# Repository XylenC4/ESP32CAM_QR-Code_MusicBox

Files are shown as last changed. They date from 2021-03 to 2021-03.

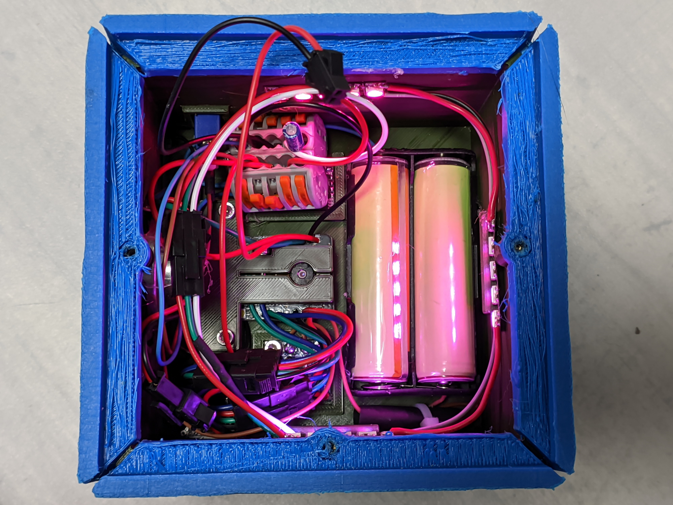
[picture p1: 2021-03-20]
Images/Inside.jpg

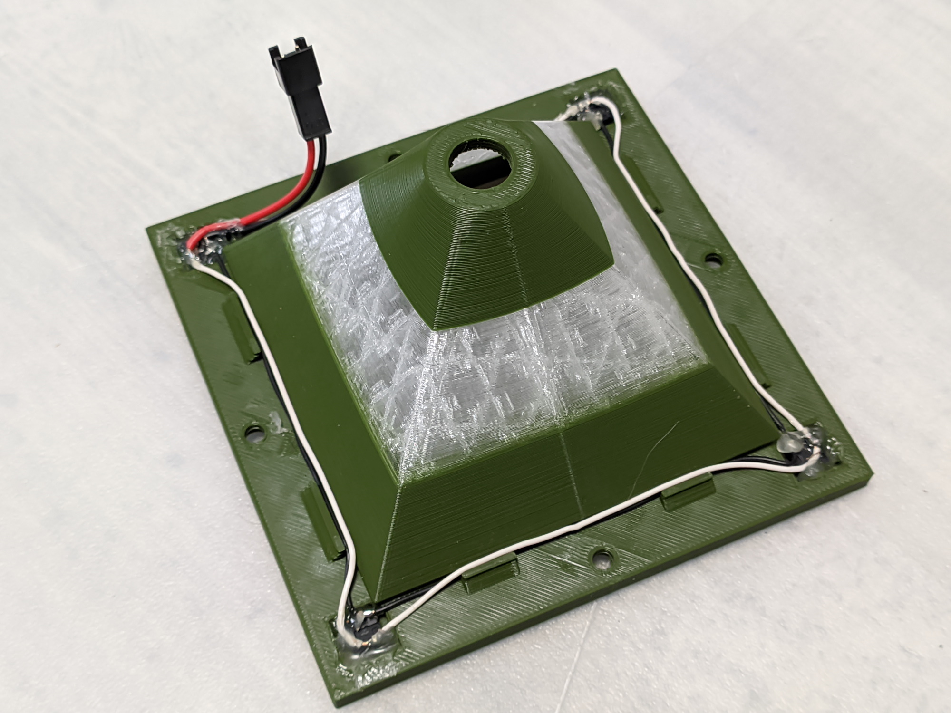
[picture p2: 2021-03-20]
Images/Funnel.jpg

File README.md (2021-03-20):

# ESP32CAM QR-Code MusicBox
This is an Kids-Toy which plays music by an QR-Code

___
# Informations
## Parts
- 1x [ESP32-CAM](https://www.aliexpress.com/wholesale?SearchText=esp32-cam)
- 1x [ESP32 WROOM 32U 16MB](https://www.aliexpress.com/wholesale?SearchText=esp32+wroom+32u+module+16mb)
- 1x [16MB SPI Flash W25Q128FVSG](https://www.aliexpress.com/wholesale?SearchText=W25Q128FVSG)
- 1x [INA226](https://www.aliexpress.com/wholesale?SearchText=ina226)
- 1x [DFPlayer mini](https://github.com/PowerBroker2/DFPlayerMini_Fast)
- 1x [5*20mm Glass Fuse fast](https://www.aliexpress.com/wholesale?SearchText=fuse+5%2B20+1A+fast)
- 1x [5*20mm Glass Fuse holder](https://www.aliexpress.com/wholesale?SearchText=glass+fuse+cable)
- 1x [18650 Charger Protection 5V Supply](https://www.aliexpress.com/wholesale?SearchText=5V+2A+Charge+Discharge)
- 1x [18650 Holder !PARALELL!](https://www.aliexpress.com/wholesale?SearchText=18650+holder+cable)
- 1x [MicroUSB Input Board](https://www.aliexpress.com/wholesale?SearchText=Micro+USB+To+DIP+Adapter)
- 1x [Micro Momentary Switches](https://www.aliexpress.com/wholesale?SearchText=Micro+Momentary+Kit+180)
- 1m [WS2812B 144LED 1M](https://www.aliexpress.com/wholesale?SearchText=ws2812b+144+led%2Fm)
- [M3x3 OD4.3mm Brass Inserts](https://www.aliexpress.com/wholesale?SearchText=brass+m3x3)
- 2x Protected 18650 cell, for example Panasonic NCR18650B. I'll recomment to buy it from a trusted shop to be geniune.
- Various M3 screws (M3x5 to M3x16)

## Used Libaries
- INA226_WE https://github.com/wollewald/INA226_WE
- DFPlayer https://github.com/PowerBroker2/DFPlayerMini_Fast
- ESPino32CAM https://github.com/ThaiEasyElec/ESPIno32CAM
- OTA Implementation: https://github.com/SensorsIot/ESP32-OTA

#ESPino32CAM Config modification
Pins-Declaration need to be audjusted in \Arduino\libraries\ESPIno32CAM\src\ESPino32CAM.h
If your LED on the board lights on, you have forgot to edit the pins!
CAMERA_MODEL_AI_THINKER
```c++
#define PWDN_GPIO_NUM     32
#define RESET_GPIO_NUM    -1
#define XCLK_GPIO_NUM      0
#define SIOD_GPIO_NUM     26
#define SIOC_GPIO_NUM     27
#define Y9_GPIO_NUM       35
#define Y8_GPIO_NUM       34
#define Y7_GPIO_NUM       39
#define Y6_GPIO_NUM       36
#define Y5_GPIO_NUM       21
#define Y4_GPIO_NUM       19
#define Y3_GPIO_NUM       18
#define Y2_GPIO_NUM        5
#define VSYNC_GPIO_NUM    25
#define HREF_GPIO_NUM     23
#define PCLK_GPIO_NUM     22
```

## OTA Implementation
A new 16MB need to be added to the configuration fole \AppData\Local\Arduino15\packages\esp32\hardware\esp32\1.X.X\boards.txt below "esp32cam.build.code_debug=0"
After Restarting the Arduino IDE you have to select the Board "AI Thinker ESP32-CAM 16MB Flash"
         
```c++
esp32cam16mb.name=AI Thinker ESP32-CAM 16MB Flash

esp32cam16mb.upload.tool=esptool_py
esp32cam16mb.upload.maximum_size=3145728
esp32cam16mb.upload.maximum_data_size=327680
esp32cam16mb.upload.wait_for_upload_port=true
esp32cam16mb.upload.speed=460800

esp32cam16mb.serial.disableDTR=true
esp32cam16mb.serial.disableRTS=true

esp32cam16mb.build.mcu=esp32
esp32cam16mb.build.core=esp32
esp32cam16mb.build.variant=esp32
esp32cam16mb.build.board=ESP32_DEV
esp32cam16mb.build.flash_size=16MB
esp32cam16mb.build.partitions=default_16MB
esp32cam16mb.build.defines=-DBOARD_HAS_PSRAM -mfix-esp32-psram-cache-issue
esp32cam16mb.build.extra_libs=-lc-psram-workaround -lm-psram-workaround
esp32cam16mb.build.code_debug=0

esp32cam16mb.menu.CPUFreq.240=240MHz (WiFi/BT)
esp32cam16mb.menu.CPUFreq.240.build.f_cpu=240000000L
esp32cam16mb.menu.CPUFreq.160=160MHz (WiFi/BT)
esp32cam16mb.menu.CPUFreq.160.build.f_cpu=160000000L
esp32cam16mb.menu.CPUFreq.80=80MHz (WiFi/BT)
esp32cam16mb.menu.CPUFreq.80.build.f_cpu=80000000L
esp32cam16mb.menu.CPUFreq.40=40MHz (40MHz XTAL)
esp32cam16mb.menu.CPUFreq.40.build.f_cpu=40000000L
esp32cam16mb.menu.CPUFreq.26=26MHz (26MHz XTAL)
esp32cam16mb.menu.CPUFreq.26.build.f_cpu=26000000L
esp32cam16mb.menu.CPUFreq.20=20MHz (40MHz XTAL)
esp32cam16mb.menu.CPUFreq.20.build.f_cpu=20000000L
esp32cam16mb.menu.CPUFreq.13=13MHz (26MHz XTAL)
esp32cam16mb.menu.CPUFreq.13.build.f_cpu=13000000L
esp32cam16mb.menu.CPUFreq.10=10MHz (40MHz XTAL)
esp32cam16mb.menu.CPUFreq.10.build.f_cpu=10000000L

esp32cam16mb.menu.FlashMode.qio=QIO
esp32cam16mb.menu.FlashMode.qio.build.flash_mode=dio
esp32cam16mb.menu.FlashMode.qio.build.boot=qio
esp32cam16mb.menu.FlashMode.dio=DIO
esp32cam16mb.menu.FlashMode.dio.build.flash_mode=dio
esp32cam16mb.menu.FlashMode.dio.build.boot=dio
esp32cam16mb.menu.FlashMode.qout=QOUT
esp32cam16mb.menu.FlashMode.qout.build.flash_mode=dout
esp32cam16mb.menu.FlashMode.qout.build.boot=qout
esp32cam16mb.menu.FlashMode.dout=DOUT
esp32cam16mb.menu.FlashMode.dout.build.flash_mode=dout
esp32cam16mb.menu.FlashMode.dout.build.boot=dout

esp32cam16mb.menu.FlashFreq.80=80MHz
esp32cam16mb.menu.FlashFreq.80.build.flash_freq=80m
esp32cam16mb.menu.FlashFreq.40=40MHz
esp32cam16mb.menu.FlashFreq.40.build.flash_freq=40m
```

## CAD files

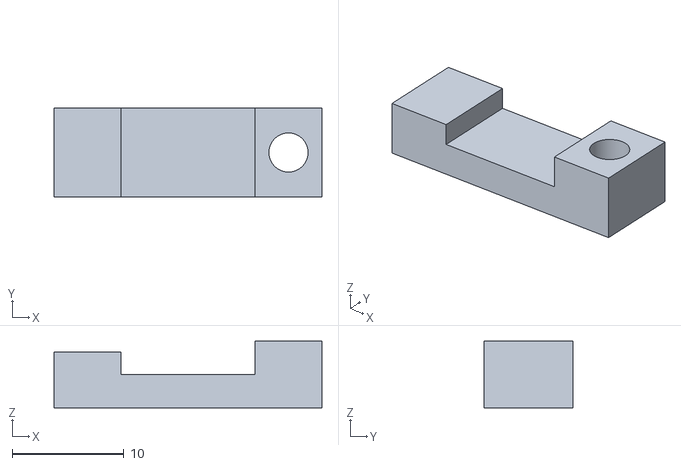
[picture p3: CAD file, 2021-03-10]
CAD-Files/DFPlayerMount.stl
24.0 x 8.00 x 6.00

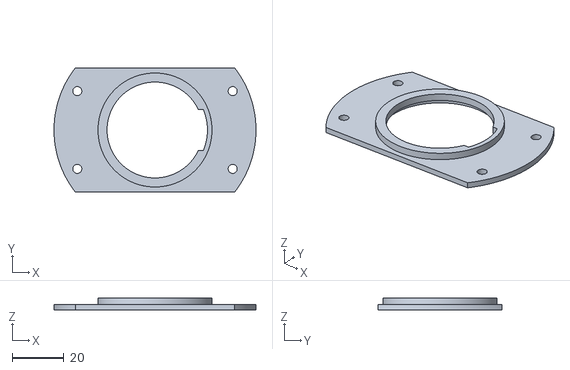
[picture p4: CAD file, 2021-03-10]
CAD-Files/SpeakerFront.stl
78.0 x 48.0 x 4.50

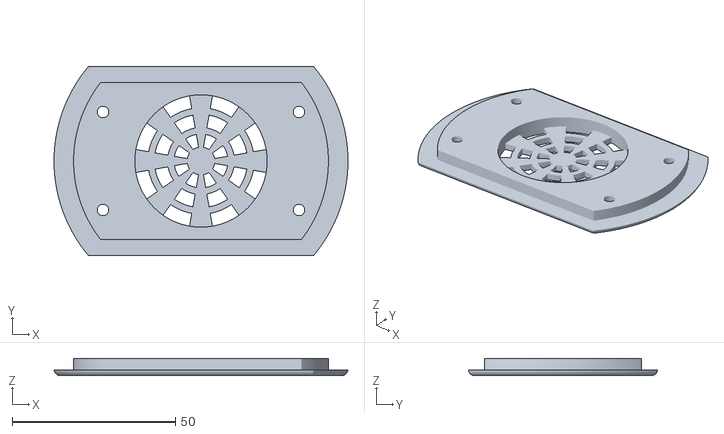
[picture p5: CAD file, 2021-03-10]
CAD-Files/SpeakerFrontTop.stl
90.0 x 58.0 x 5.30

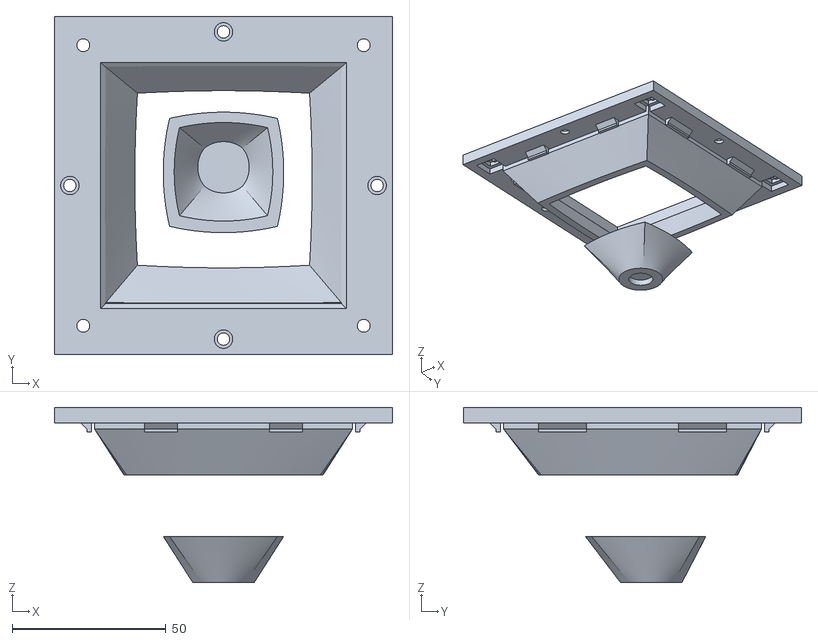
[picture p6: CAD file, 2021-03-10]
CAD-Files/InnerCoverColor.stl
110.0 x 110.0 x 57.0

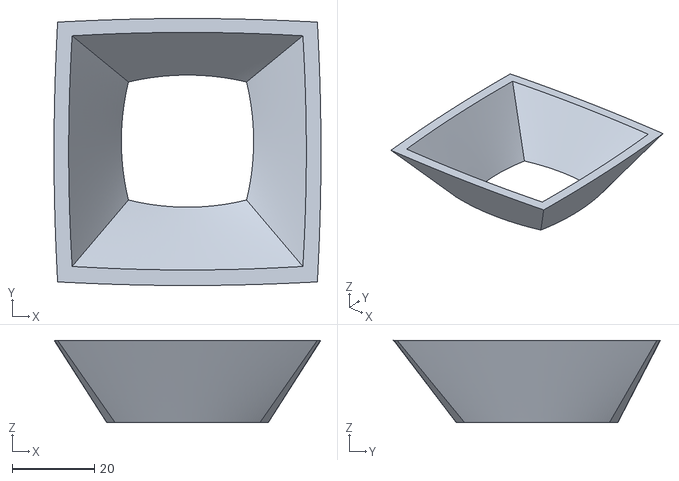
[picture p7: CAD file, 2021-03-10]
CAD-Files/InnerCoverTransparent.stl
64.8 x 64.8 x 20.0

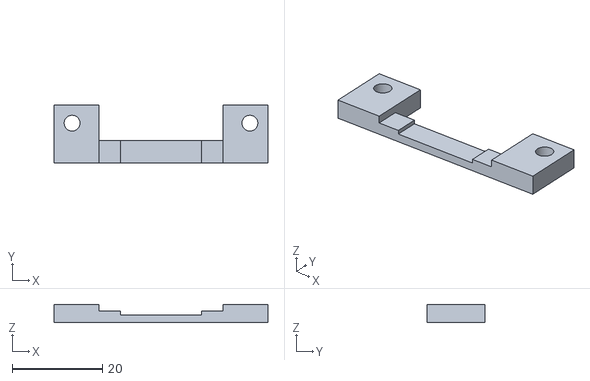
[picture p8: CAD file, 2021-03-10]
CAD-Files/ESP32MountBottom.stl
47.3 x 12.8 x 4.00

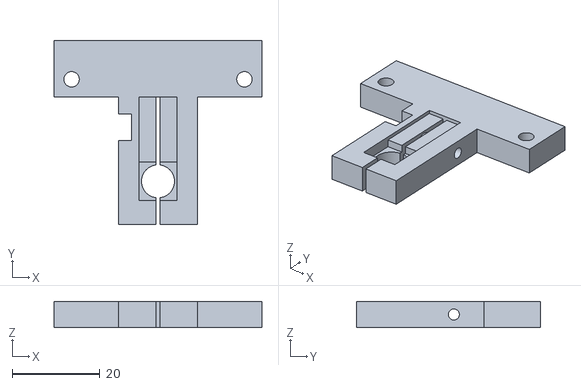
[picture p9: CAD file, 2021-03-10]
CAD-Files/ESP32CamMount.stl
47.3 x 41.8 x 6.00

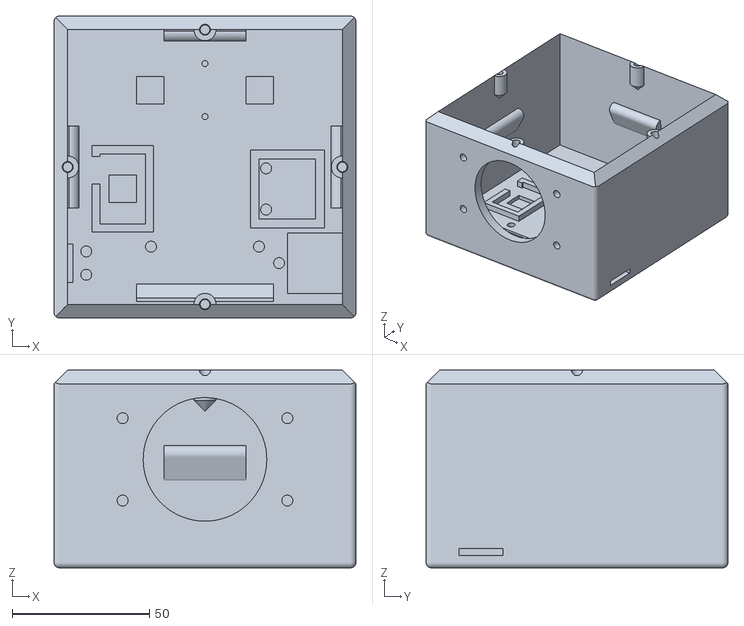
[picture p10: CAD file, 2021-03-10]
CAD-Files/Box.stl
110.0 x 110.0 x 72.0

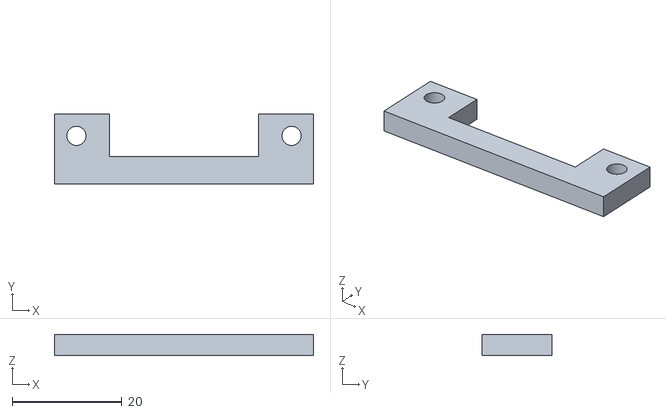
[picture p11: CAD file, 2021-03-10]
CAD-Files/ESP32MountMiddle.stl
47.3 x 12.8 x 3.90

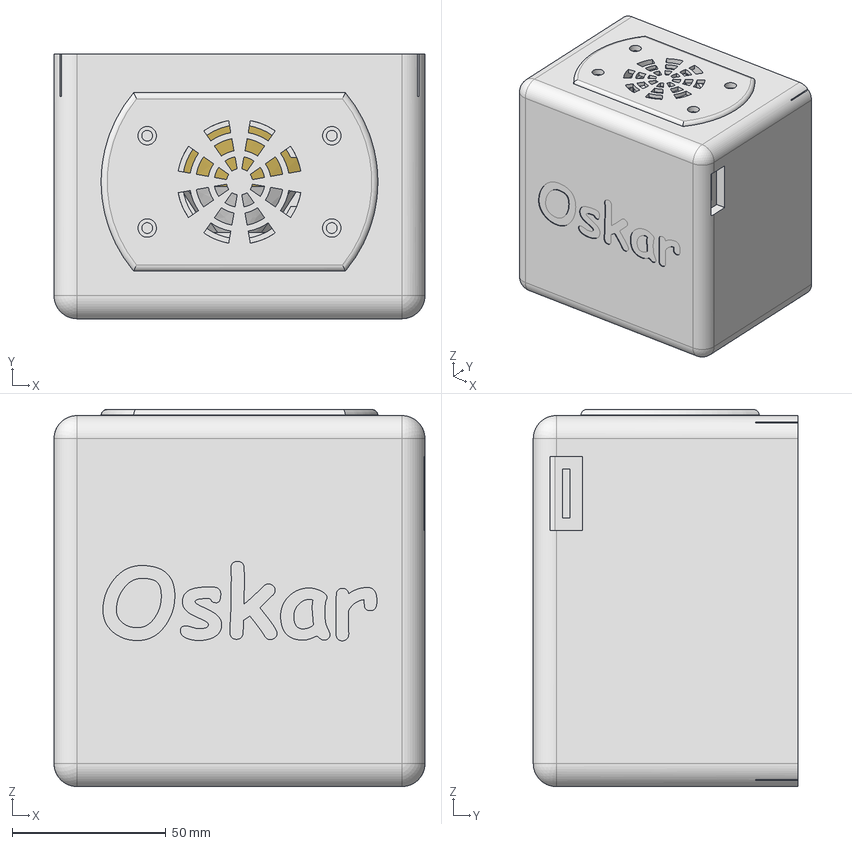
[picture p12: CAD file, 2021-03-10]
CAD-Files/ESP32-CAM MusicBox.step
120.6 x 86.0 x 122.6 mm
ESP32CamMount
ESP32CamMount_1
MP3PlazerMOunt
SpeakerFront
SpeakerFrontTop
TPU_Sleeve
InnerCoverColor
InnerCoverTransparent

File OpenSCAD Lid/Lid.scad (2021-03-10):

include <Chamfer.scad>;

$fn=15;
generator_color=100;

top_size=110; //110
bottom_outer_size=79.5;
bottom_outer_height=1;

bottom_inner_size=79.5;
bottom_inner_hole_size=65.0;
bottom_inner_height=2.5;

edge_radius=2;

stl_offset=0.1;
stl_files=5;
stl_name=str("PathCow"); //_NUMBER.svg will be automatically added
stl_colors=["black","red","blue","green","yellow","gray"];
stl_overlap=0.005;


upper_cover=0.35;
upper_min_height=5;
upper_start_height=upper_min_height - stl_files*stl_offset-stl_offset;
upper_filler= upper_min_height - upper_start_height;

screw_hole_lid_radius=2/2;
screw_hole_radius=1.6/2;
screw_hole_height=10;


if(generator_color == -1) {
 get_inner();
}
else if(generator_color < 100) {
 get_inner_part(generator_color);
}

if(generator_color == -1 || generator_color == 100){
 difference(){  
  get_body_upper();
  get_screw_hole(-5,screw_hole_radius);
 }
}

if(generator_color == -1 || generator_color == 101){
 difference(){  
  get_middle_lower_body();
  get_screw_hole(-5,screw_hole_radius);
 }
}

if(generator_color == -1 || generator_color == 102){
 difference(){  
  get_lower_lid();
  get_lower_lid_hole();
 }
 
}

module get_body_upper() {
 get_upper_body();
}

module get_middle_lower_body() {
 get_middle_body();
 get_lower_body();  
}

module get_inner() {
 for (i=[0:stl_files-1])
 get_inner_part(i);
}

module get_inner_part(i) {
 act_height = upper_start_height+stl_offset*i-stl_overlap/2;
 stl_instance = str(stl_name, "_", i, ".svg");
 echo(stl_instance);
 color(stl_colors[i])
  translate([0, 0, act_height])
   linear_extrude(height = stl_offset+stl_overlap)
    import(file = stl_instance, center = false, dpi = 96);
}


module get_upper_body() {
 difference() {
  translate([-top_size/2, -top_size/2, upper_start_height])
   roundedcube(top_size,top_size,stl_offset*stl_files+upper_cover,edge_radius);
  get_inner();
 }
}

module get_middle_body() {
  translate([-top_size/2, -top_size/2, 0])
   roundedcube(top_size,top_size,upper_start_height,edge_radius);
}

module get_lower_body(){
 translate([-bottom_outer_size/2, -bottom_outer_size/2, -bottom_outer_height])
 roundedcube(bottom_outer_size,bottom_outer_size,bottom_outer_height,edge_radius);
}

module get_lower_lid(){ 
 difference(){  
  translate([-bottom_inner_size/2, -bottom_inner_size/2, -bottom_outer_height-bottom_inner_height])
  roundedcube(bottom_inner_size,bottom_inner_size,bottom_inner_height,edge_radius); 

  get_screw_hole(-5,screw_hole_lid_radius);
 }
}

module get_lower_lid_hole(){    
 translate([-bottom_inner_hole_size/2, -bottom_inner_hole_size/2, -bottom_outer_height-bottom_inner_height-0.5])
  cube([bottom_inner_hole_size,bottom_inner_hole_size,bottom_inner_height+1]); 
}

module get_screw_hole(height, radius){
mirror([0,0,0])
 translate([bottom_inner_size/2+height, bottom_inner_size/2+height, +height])
  chamferCylinder(r=radius, r2=radius, h=screw_hole_height, ch=-2.5, ch2=2);

mirror([1,0,0])
 translate([bottom_inner_size/2+height, bottom_inner_size/2+height, +height])
  chamferCylinder(r=radius, r2=radius, h=screw_hole_height, ch=-2.5, ch2=2);

mirror([0,1,0])
 translate([bottom_inner_size/2+height, bottom_inner_size/2+height, +height])
  chamferCylinder(r=radius, r2=radius, h=screw_hole_height, ch=-2.5, ch2=2);

mirror([1,1,0])
 translate([bottom_inner_size/2+height, bottom_inner_size/2+height, +height])
  chamferCylinder(r=radius, r2=radius, h=screw_hole_height, ch=-2.5, ch2=2);

}


//by Chris Bate https://www.youtube.com/watch?v=gKOkJWiTgAY
module roundedcube(xdim ,ydim ,zdim,rdim){
hull(){
translate([rdim,rdim,0])cylinder(h=zdim,r=rdim);
translate([xdim-rdim,rdim,0])cylinder(h=zdim,r=rdim);

translate([rdim,ydim-rdim,0])cylinder(h=zdim,r=rdim);
translate([xdim-rdim,ydim-rdim,0])cylinder(h=zdim,r=rdim);
}
}

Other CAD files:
OpenSCAD Lid/chamfer.scad

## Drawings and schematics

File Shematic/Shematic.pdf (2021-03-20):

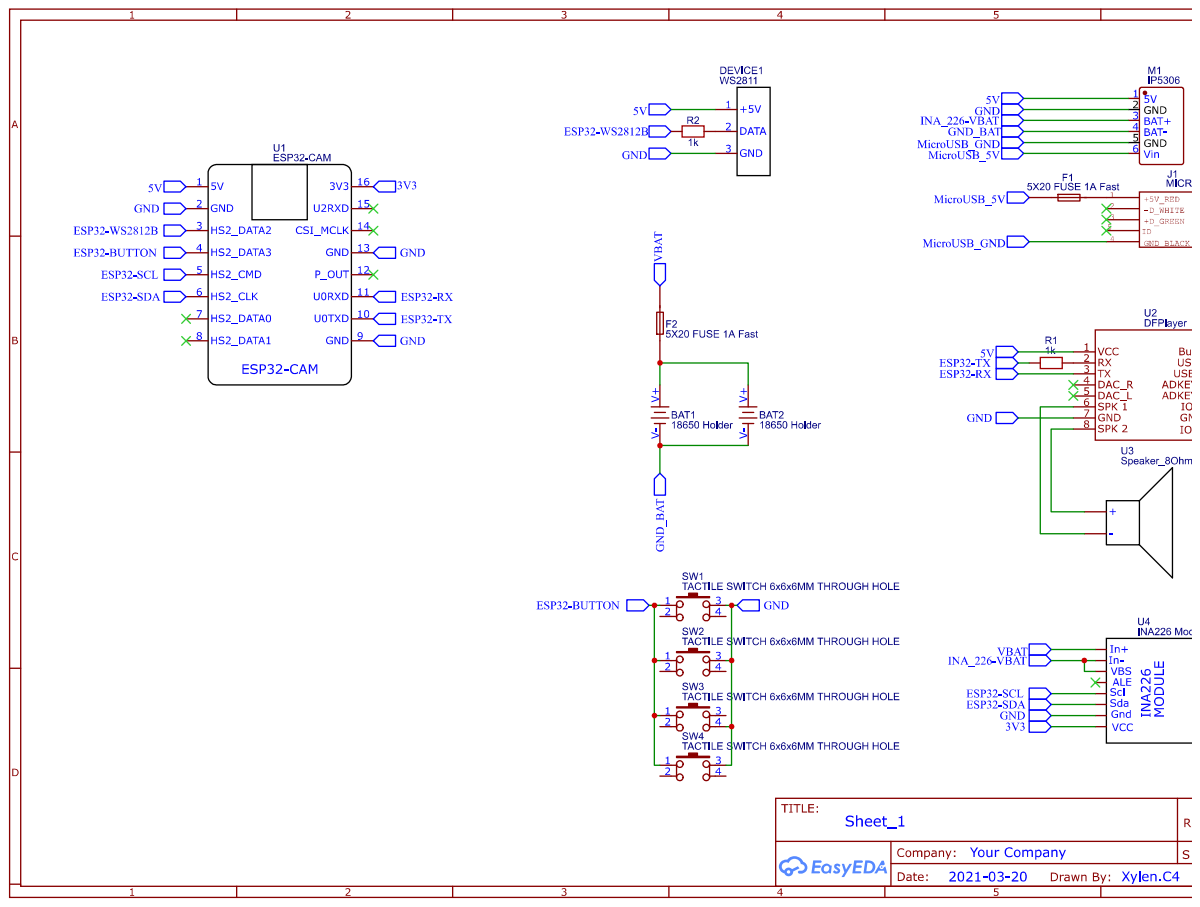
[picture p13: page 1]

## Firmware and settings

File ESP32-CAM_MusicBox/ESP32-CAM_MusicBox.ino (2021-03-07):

//#define ESP32_RTOS  // Uncomment this line if you want to use the code with freertos only on the ESP32
// Has to be done before including "OTA.h"
#include "OTA.h"
#include "FastLED.h"
#include "credentials.h"


// Push button on Boot to enable WIFI without running the actual scetch (failsafe).
// Push the button again to run the scetch with enabled WIFI for debugging.
#define BUTTON_DEBUG 13
#define BUTTON_QR BUTTON_DEBUG
bool bEnableDebug = false;
bool bStartUp = false;

uint32_t entry;

void setup() {
  // Disable the Onboard LED
  pinMode(4, OUTPUT);
  digitalWrite(4, LOW);    // turn the LED off by making the voltage LOW

  // Set-Up the top-lid pushbutton
  pinMode(BUTTON_DEBUG, INPUT_PULLUP);    // sets the digital pin 13 as output

  setup_FastLED();

  if (!digitalRead(BUTTON_DEBUG)) {
    bEnableDebug = true;
    bStartUp = true;
    setupOTA("ESP32-CAM_MusicBox", mySSID, myPASSWORD);
  }

  while (bStartUp) {
#ifndef defined(ESP32_RTOS) && defined(ESP32)
    TelnetStream.println(String("Upload mode active: ") + String(millis() / 1000) + String("s"));
    ArduinoOTA.handle();
#endif

    FastLEDColor(CRGB::Fuchsia);
    // Positive flank to enable the program in debug mode
    bool bButtonDebug = !digitalRead(BUTTON_DEBUG);
    static bool bButtonDebugTemp = bButtonDebug;
    if (!bButtonDebugTemp && bButtonDebug) {
      bStartUp = false;
    }
    bButtonDebugTemp = bButtonDebug;
    delay(500);
  }

  //Set-Up functions
  FastLEDColor(CRGB::Blue);
  setup_INA226();
  FastLEDColor(CRGB::Green);
  setup_DFPlayer();
  FastLEDColor(CRGB::Yellow);
  setup_QRCode();
}

void loop() {
  if (bEnableDebug) {
    entry = micros();
#ifndef defined(ESP32_RTOS) && defined(ESP32)
    ArduinoOTA.handle();
#endif

//    TelnetStream.println(micros() - entry);
//    TelnetStream.println("Loop");
  }

  //Loop functions
  loop_FastLED();
  loop_INA226();
  loop_DFPlayer();
  loop_QRCode();

  // Your code here
}

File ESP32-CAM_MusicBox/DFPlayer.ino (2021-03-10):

#include <DFPlayerMini_Fast.h>

void printError();

#define VOLUME 15 //Set volume value (0~30).
int oldFolderNr = -1;
bool bRegister[255]; //Played files register
int16_t iRegister[99]; //Folder count register


DFPlayerMini_Fast myMP3;

void setup_DFPlayer()
{

  TelnetStream.println("DFPlayer: Initialisation");
  Serial.begin(9600);
  delay(500); // Initialisation delay
  myMP3.begin(Serial);

  while (myMP3.currentMode() < 0) {
    TelnetStream.println("DFPlayer: No response -> SDCard inseret?");
    FastLEDColor(CRGB::Red);
  }

  if (myMP3.numSdTracks() <= 0) {
    TelnetStream.println("DFPlayer: No files on the SDCard");
    FastLEDColor(CRGB::Red);
    delay(10000);
    ESP.restart();
  }

  TelnetStream.println("DFPlayer: Online");

  myMP3.volume(VOLUME);

  //Init folder count register
  for ( int i = 0; i < 1000; i++) {
    iRegister[i] = -1;
  }
}

void loop_DFPlayer()
{
  printError();
}

//Play a file
void DFPlayerPlay(int Nr) {
  myMP3.volume(VOLUME);  //Set volume value (0~30).
  if (Nr >= 0 && Nr <= 65000) {
    TelnetStream.println(String("DFPlayer: play: SD\\mp3\\") + Nr + String(".mp3"));
    myMP3.playFromMP3Folder(Nr);
  }
}

//Play a random file in a defined folder
void DFPlayerPlayFolderRandom(int FolderNr) {
  if (FolderNr!=50) {
    myMP3.volume(VOLUME);  //Set volume value (0~30).
  }
  else {
    myMP3.volume(30);  //Set volume value (0~30).
  }
  int FilesInFoler = DFPlayerGetFolderCount(FolderNr);

  if (FilesInFoler < 0) {
    return;
  }

  // Reset the register if the folder has changed
  if (FolderNr != oldFolderNr) {
    DFPlayerResetRegister();
  }
  if (DFPlayerIsAllPlayed(FilesInFoler)) { // Reset the register if all songs are already played
    DFPlayerResetRegister();
  }

  int TrackNr = DFPlayerRandomTrackFromRegister(FilesInFoler) + 1;

  myMP3.playFolder(FolderNr, TrackNr); //play specific mp3 in SD:/02/004.mp3; Folder Name(1~10); File Name(1~1000)
  oldFolderNr = FolderNr;
  DFPlayerShowRegister(FilesInFoler);
}

// My DFPlayer has quite often issues to read the file count and returns a -1
// This function will aqquire the folder number and stored the result.
int DFPlayerGetFolderCount(int FolderNr) {
  if (iRegister[FolderNr] == -1) {
    for ( int i = 0; i < 10; i++) {
      // Workarount because the DFPlayer returns at least one time the told value again.
      myMP3.numTracksInFolder(FolderNr);
      delay(100);
      myMP3.numTracksInFolder(FolderNr);
      delay(100);
      int FilesInFoler = myMP3.numTracksInFolder(FolderNr);
      TelnetStream.println(String("DFPlayer: Get file count of folder:") + FolderNr + String("-") + FilesInFoler);
      if (FilesInFoler == -1) {
        delay(100);
      }
      else {
        iRegister[FolderNr] = FilesInFoler;
        break;
      }
    }
  }
  TelnetStream.println(String("DFPlayer: FileCount:") + iRegister[FolderNr]);
  return iRegister[FolderNr];
}

// Reset
void DFPlayerResetRegister() {
  for ( int i = 0; i < 255; i++) {
    bRegister[i] = false;
  }
}

// Check if all tracks are already played
bool DFPlayerIsAllPlayed(int MaxTrackNr) {
  for ( int i = 0; i < MaxTrackNr; i++) {
    TelnetStream.println("DFPlayer: IsPlayed [i]:" + String(i) + "-" + String(bRegister[i]));
    if (bRegister[i] == false) {
      return false;
    }
  }
  TelnetStream.println("true");
  return true;
}

// Play random file
int DFPlayerRandomTrackFromRegister(int MaxTrackNr) {
  // Only try randomize MaxTrackNr*2 times to reduce the changse of a lockup
  for ( int i = 0; i < MaxTrackNr * 2; i++) {
    int rnd = random(0, MaxTrackNr);
    if (!bRegister[rnd]) {
      TelnetStream.println("DFPlayer: Play Random [i]:" + String(i) + "[rnd]:" + String(rnd));
      bRegister[rnd] = true;
      return rnd;
    }
  }
  return DFPlayerNextNotPlayedFromRegister(MaxTrackNr);
}

// Wen radomization has failed play the next one
int DFPlayerNextNotPlayedFromRegister(int MaxTrackNr) {
  for ( int i = 0; i < MaxTrackNr; i++) {
    if (!bRegister[i]) {
      TelnetStream.println("DFPlayer: NextFromRegister [i]:" + String(i));
      return i;
    }
  }
  return 0;
}

void DFPlayerShowRegister(int MaxTrackNr) {
  for ( int i = 0; i < MaxTrackNr; i++) {
    TelnetStream.println("DFPlayer: [" + String(i) + "]:" + String(bRegister[i]));
  }
}


void printError()
{
  if (myMP3.recStack.commandValue == 0x40)
  {
    switch (myMP3.recStack.paramLSB)
    {
      case 0x1:
        {
          TelnetStream.println("DFPlayer: Module busy (this info is returned when the initialization is not done)");
          break;
        }
      case 0x2:
        {
          TelnetStream.println("DFPlayer: Currently sleep mode(supports only specified device in sleep mode)");
          break;
        }
      case 0x3:
        {
          TelnetStream.println("DFPlayer: Serial receiving error(a frame has not been received completely yet)");
          break;
        }
      case 0x4:
        {
          TelnetStream.println("DFPlayer: Checksum incorrect");
          break;
        }
      case 0x5:
        {
          TelnetStream.println("DFPlayer: Specified track is out of current track scope");
          break;
        }
      case 0x6:
        {
          TelnetStream.println("DFPlayer: Specified track is not found");
          break;
        }
      case 0x7:
        {
          TelnetStream.println("DFPlayer: Insertion error(an inserting operation only can be done when a track is being played)");
          break;
        }
      case 0x8:
        {
          TelnetStream.println("DFPlayer: SD card reading failed(SD card pulled out or damaged)");
          break;
        }
      case 0xA:
        {
          TelnetStream.println("DFPlayer: Entered into sleep mode");
          break;
        }
      default:
        {
          TelnetStream.print("DFPlayer: Unknown error: ");
          TelnetStream.println(myMP3.recStack.paramLSB);
          break;
        }
    }
  }
}
